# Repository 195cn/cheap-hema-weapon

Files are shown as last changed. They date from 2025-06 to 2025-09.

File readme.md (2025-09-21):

# 廉价HEMA武器计划

```
Author      : 195
Create Date : 2025/6/1

Version:     

    2025/9/21 V2.0 增加了武装剑，小圆盾。并且自研了免焊穿心刀根。
    2025/6/8  V1.1 实战测试，增加特大碗护手。
    2025/6/1  V1.0 初版军刀，圆盘D护版。

```

## 📜 开源声明（Unlicense协议）

本项目遵循 **[Unlicense协议](https://unlicense.org/)**，您享有完全自由的使用权：

- ✅ **无限制使用**：可自由复制、修改、分发，包括商业用途。
- ✅ **无需署名**：不强制要求保留作者信息或声明。
- ✅ **闭源兼容**：允许将本模型整合至闭源项目中。
- ⚠️ **法律免责**：  
  本作品按“现状”提供，**无任何明示或暗示担保**，包括但不限于：  
  - ✅ 适用性担保（不保证适用于您的特定场景）  
  - ✅ 安全性担保（不保证无漏洞或安全隐患）  
  - ✅ 合规性担保（不保证符合所有地区法律法规）  
  作者明确不承担因使用本模型产生的任何责任，包括但不限于直接损失、间接损失或法律纠纷。

## 不对任何安全问题负责，请自负一切后果

# 说明

DIY廉价入门装备，以满足对练需求。

非史诗设计，尽量采用现代工业的廉价材料。

在保证重心和减伤以外，尽量的便宜，不保证其他性能。

# Feature

- 总成本百元左右
- 刀条板材切割（淘宝代工方便）
- 护手板材切割/钣金（便宜，代工方便）
- ~~龙骨柄（穿心柄/老鼠尾需要焊接螺纹）~~
- 自研免焊穿心刀根
- 打印握把
- 打印安全头
- 加长握把（匹配195身高手型）

# 设计理念

本人并非Hema爱好者，而是生存狂菜刀党。
练hema的目的是储备械斗能力，以便在抢劫的时候用。
尽可能的避免双杀。
需要考虑室内作战，并且便于携带。
需要有压制常规生活武器的能力。
目标为城市非农非兵人口（打不过）。
因长枪和草叉等太过imba，不考虑单刀进枪之类的东西。

主要假想对向武器：
- 匕首
- 短棍
- 长棍
- 砍刀
- 柴刀/菜刀

并且要保证武器廉价易得，技术可复用到常见生活刀型，如卢旺达甘蔗刀，18剁等。

因大碗军刀独特的自带护手带来的绝佳防御，所以选择军刀作为技术基础。
而且在hema中联系人数较多，便于训练。

其实原来是练日刀的，因训练规矩太多，放弃了。
身体原因无法正坐，裸足训练，竹刀手感差异太大。

其他备选：
- 梅瑟德砍（护手容易制作）
- 手半剑（十字护手容易制作）
- 日刀（护手容易制作/大货多）

因个人体质问题，由于身高导致的手掌宽大，并且需要适应大号冰球手。
所以握把都相对较长。

# 版本

## V2.0

这是个里程碑的版本，以往最麻烦的刀根尾部焊接螺丝的问题得到了解决。

先用武装剑来进行测试，短期测试内，刀根并没有出现断裂等其他问题。

通过切割结构+螺纹杆+圆柱螺母，实现了免焊接的刀根尾部螺丝固定，这样就可以和史实刀剑一样固定剑格和配重球，或是护手。

### 武装剑

```

武装剑\V1\训练剑V1_65Mn硬料_3mm_20250907.dxf
武装剑\V1\细柄45mm球.stp
武装剑\V1\粗柄40mm球.stp

```

已经经过了实战测试。

模块化设计，可以自行改变剑柄（包括长度），剑格，配重，实现不同的重心配置。

剑条通过军刀刀条修改，减伤，手感无明显变化。增加指盾，重心稍微后移。

综合成本60左右。

材料清单： 

- 圆柱螺母x2 M6x12x10 (关键字 铁加长螺母圆柱螺母套管连接焊接螺母柱丝杆接头)
- 不锈钢球x1 直径38mm~45mm（关键字 304不锈钢实心打孔钢球带孔球通孔钻孔穿孔钢珠）
- M6螺纹杆 长度180mm
- M6垫片，六角螺母

重心：

- 用45mm不锈钢球配重，总重935g，重心5cm。
- 用38mm不锈钢球配重，总重785g，重心9cm。
- 还有40mm不锈钢球，没实际测，推测总重820g，重心7左右

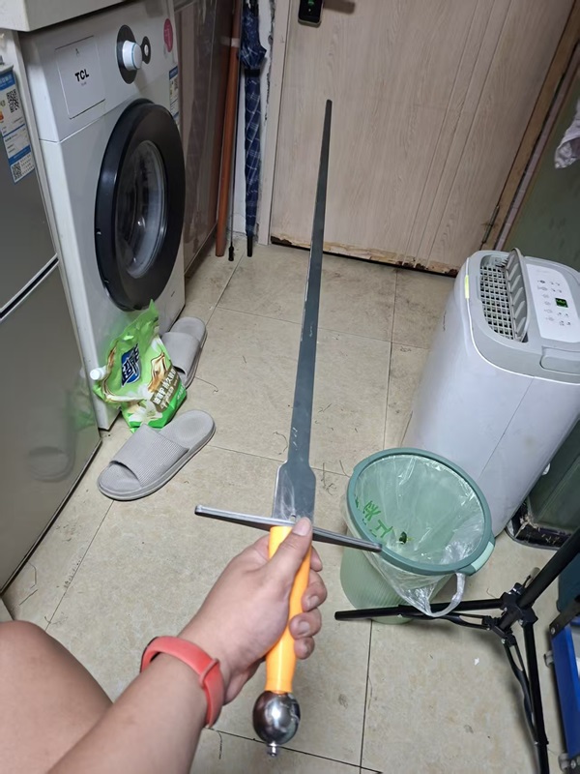
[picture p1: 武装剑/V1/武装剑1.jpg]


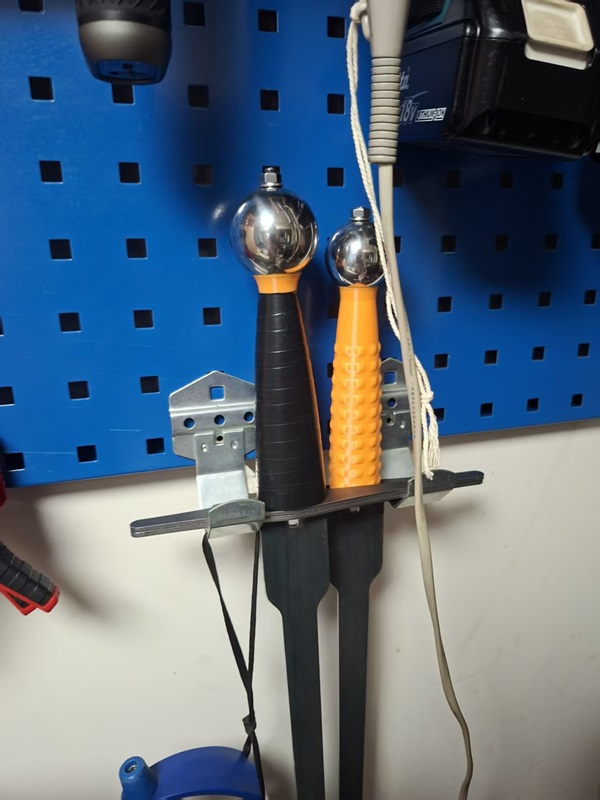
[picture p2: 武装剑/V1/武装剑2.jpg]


### 小圆盾

```

小圆盾\V1\训练盾V1_65Mn硬料_2mm_20250921.dxf
小圆盾\V1\圆盾把手.stp

```

未经过实战测试，打样途中。

全金属设计，盾帽使用不锈钢盆，并在盆底增加2mm厚的叠加甲片。

综合成本60左右。

材料清单： 

- 肉蟹煲盆 直径22cm (关键字 胖哥俩馋胖不锈钢肉蟹煲专用盆商用虾蟹煲盆酸菜鱼水煮鱼小龙虾盆)

木制版本测试后发现工序过于复杂，但是手感尚可。

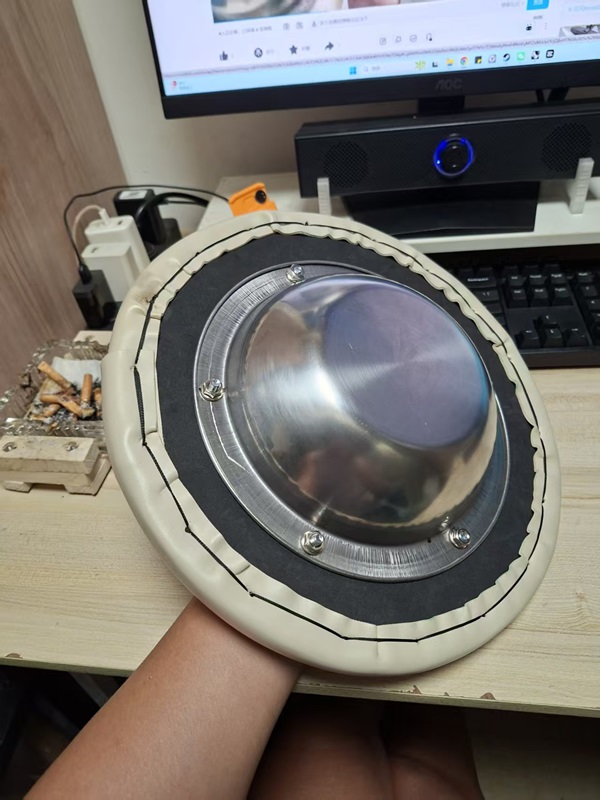
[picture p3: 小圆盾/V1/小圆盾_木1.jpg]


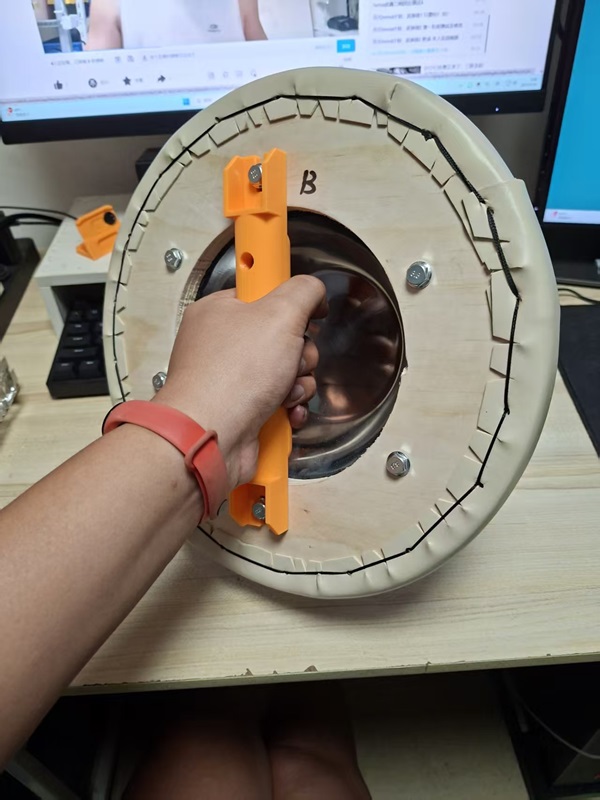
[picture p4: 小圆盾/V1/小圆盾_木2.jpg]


### 军刀

未改动，移动到独立文件夹。

暂时没有日程修改。不过最近测试了喷枪热弯，似乎可以用于自制军刀D护。

我个人不建议做这个版本了，缺点太多了。

### 通用模型

通过刀根开槽，卡住两个圆柱螺母，并且通过打印刀柄内部开槽实现了约束。

可以自由调整螺纹杆的长度，以配合不同刀柄。

V1,V2 所需的圆柱螺母尺寸为： M6x12x10 (关键字 铁加长螺母圆柱螺母套管连接焊接螺母柱丝杆接头)

- 基础刀根——测试用，为原军刀刀根，已废弃。
- 通用刀根V1，较细的早期版本，装配测试过，但处于强度考虑，武装剑没有采用。
- 通用刀根V2，武装剑加粗版本，已实战测试。

通用刀根V2的刀根宽处为26mm，手柄宽度最小建议32mm以上。

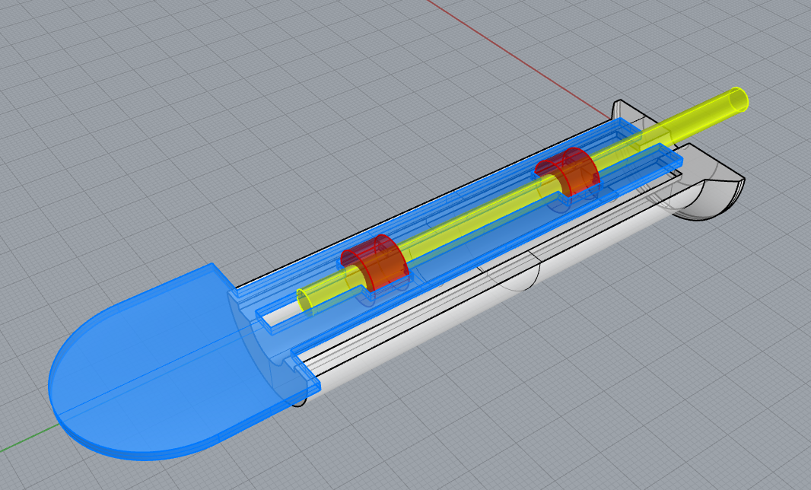
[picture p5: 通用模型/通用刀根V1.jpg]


## V1.1

经过实战测试。

- 刺击减伤和斩击减伤都得到认可。
- 刀身有点弹，但普遍可以接受。
- 两个护手版本，评价还算可以。
- 握把太圆太细，待修改
- 安全头强度不够，待修改。

### 护手

增加了特大碗,碗重615g，总重1150g，重心8cm。

经过测试，手感评价可以，防护力非常好。

虽然很重，但是还是放出来供参考。

```
V1\护手_002_特大碗.stp
```

## V1

整体重量900g左右，重心13cm。

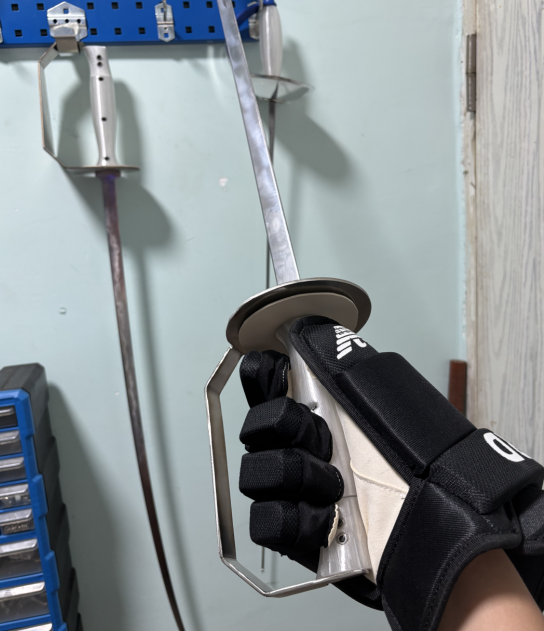
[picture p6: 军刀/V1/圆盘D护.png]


为下图最后两把“圆盘D护”

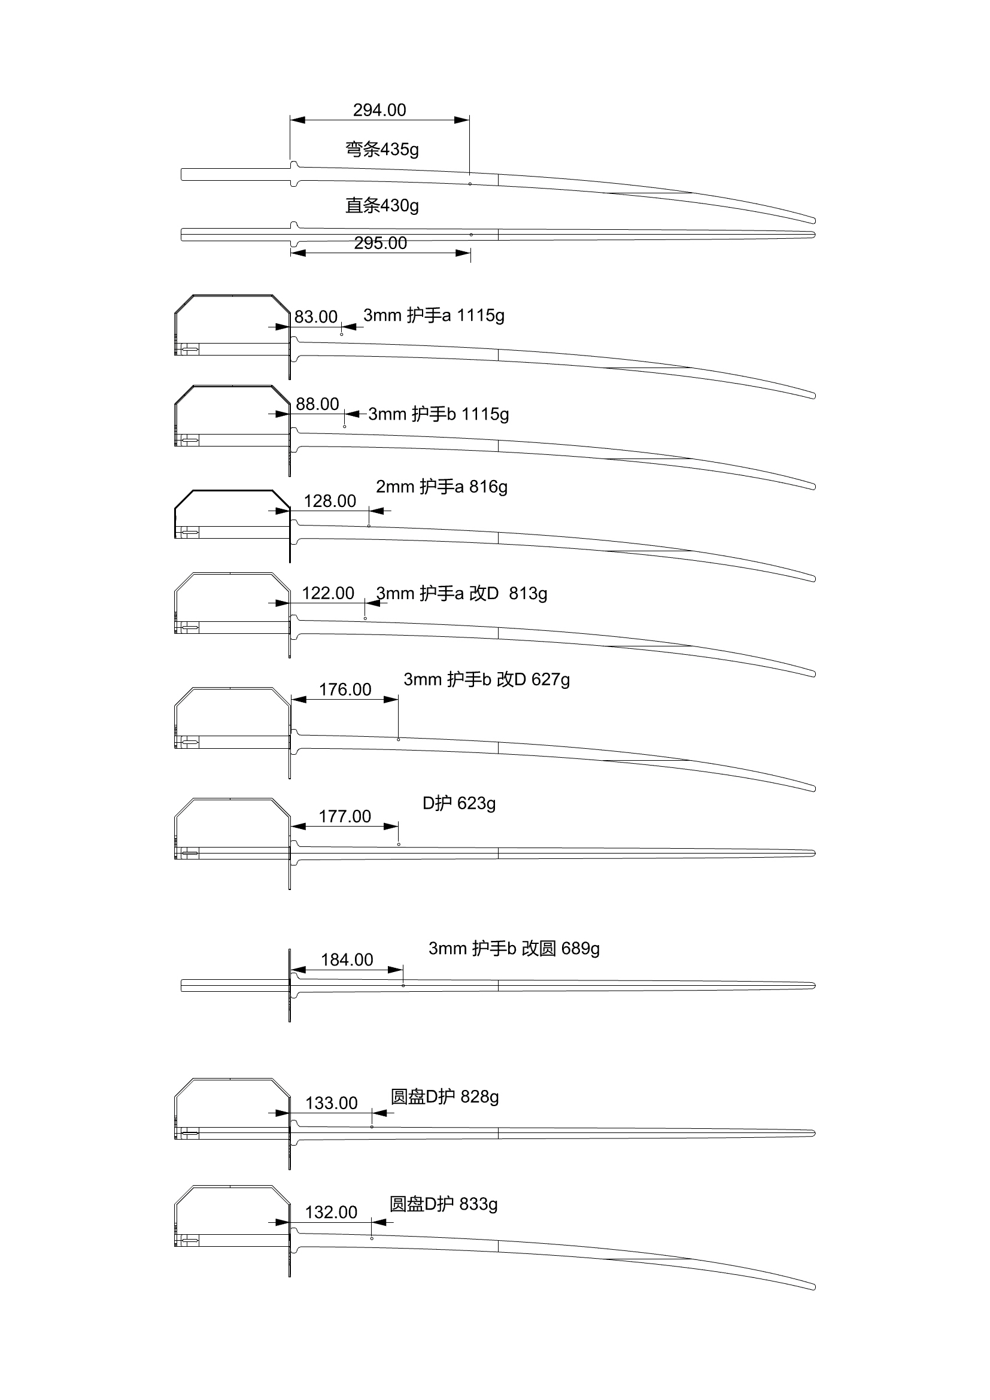
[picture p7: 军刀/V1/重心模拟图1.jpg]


### 刀条

分别设计了直刀和弯刀，材质为3mm厚的65Mn（弹簧钢）淬火硬料。

```
V1\弯刀条_3mm_65Mn硬料.dxf
V1\直刀条_3mm_65Mn硬料.dxf
```

- 龙骨刀根
- 刺击减伤9.5kg
- 斩击减伤**未测试**

### 护手

找淘宝可以接受stp模型的钣金代工商家，我不会画钣金图。

材质测试用的304不锈钢，但A3，弹簧钢应该都可以。

```
V1\护手_001_圆盘D护.stp
```

打样了2种护手，3mm厚不锈钢，重量为615g左右，过重。

重心问题比较严重，重心严重偏离刀身，转动惯量过大。

临时用角磨机切割了一个，重量减少为410g左右。

经测试手感良好。

模型为切割后的版本，但感觉不伦不类的，已经不是军刀的大碗了，更像spadroon。

### 握把

建议壁厚4，填充20%。

```
V1\大碗通用握把_V1.stp
```

纺锤形，尽量贴近实战型而不是竞技型。

用M4柱头螺栓和六角螺母固定，长度忘了应该是M4*18吧，忘了，你们多买几种吧，嘻嘻。

握把和护手中间需要垫一块厚度1mm~1.5mm的皮革或者其他布料，面巾纸也行。

护手开槽长22mm，刀根宽20mm，为了便于安装，这就造成了装好后护手会前后动。

搞个东西压在握把和护手中间，就可以增加摩擦力，也可以防止拇指磕到护手。

# 计划

## V1阶段（已完成）

尝试65Mn均厚刀条是否可以用于兵击训练。

- 65Mn弹簧钢均厚刀条（完成）
- 刺击减伤测试（完成）
- 斩击减伤测试（V1.1完成）
- 空挥手感测试（V1.1完成）
- 实战测试（V1.1完成）
- 钣金护手（算完成了，这个版本就这样）
- 打印安全头（完成，测试耐久不高）
- 打印握把（完成）
- 大碗护手重新设计
- 握把优化
- 其他潜在的优化

需要实战训练，咨询馆内兵击老手意见。

预计空挥一个月，对练两场。

优化整体设计，对标400~800水平大货军刀。

## V2阶段（进行中）

了解梅瑟，手半剑，中剑等结构，调研/打样。

- 直剑+十字格类型（完成）
- 大弧度刀条，波刀
- 反曲刀刀条
- 德砍

## V3阶段

开刃试斩，刀鞘携具。

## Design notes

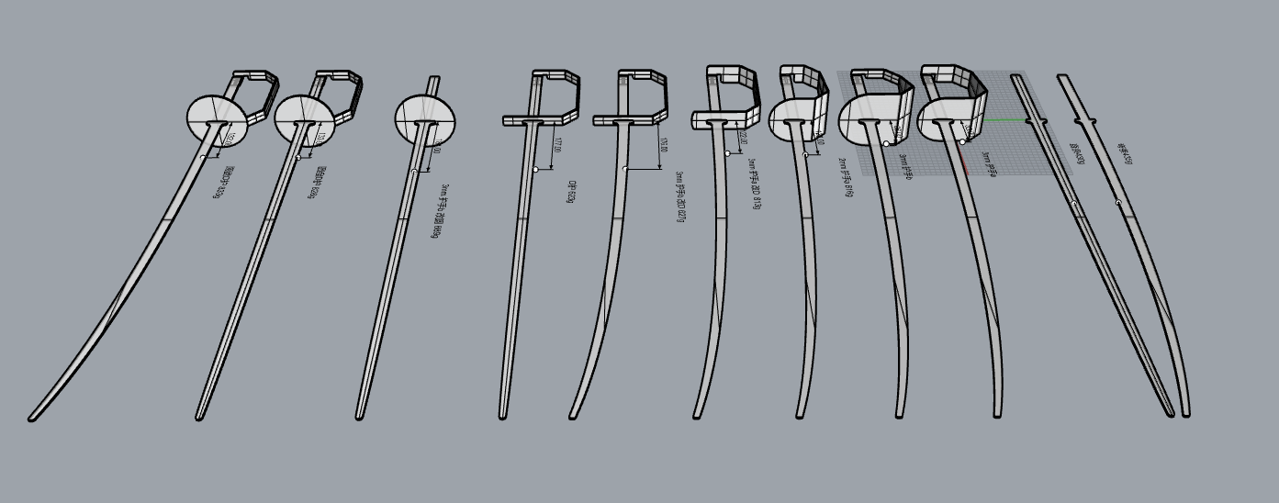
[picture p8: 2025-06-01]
军刀/V1/重心模拟图2.png

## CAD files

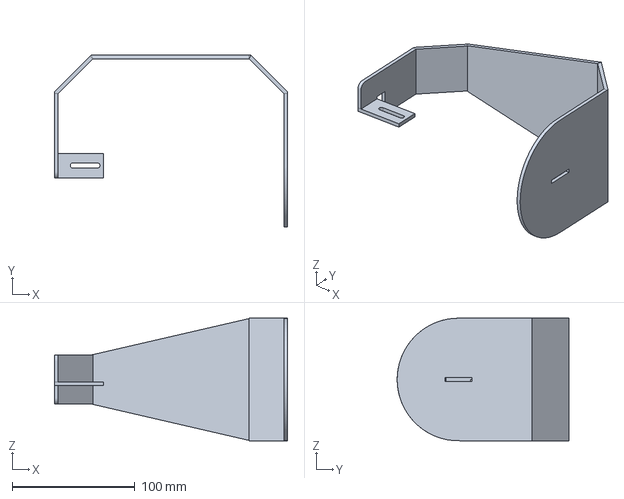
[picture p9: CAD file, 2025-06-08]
军刀/V1/护手_002_特大碗.stp
190.0 x 140.0 x 100.0 mm

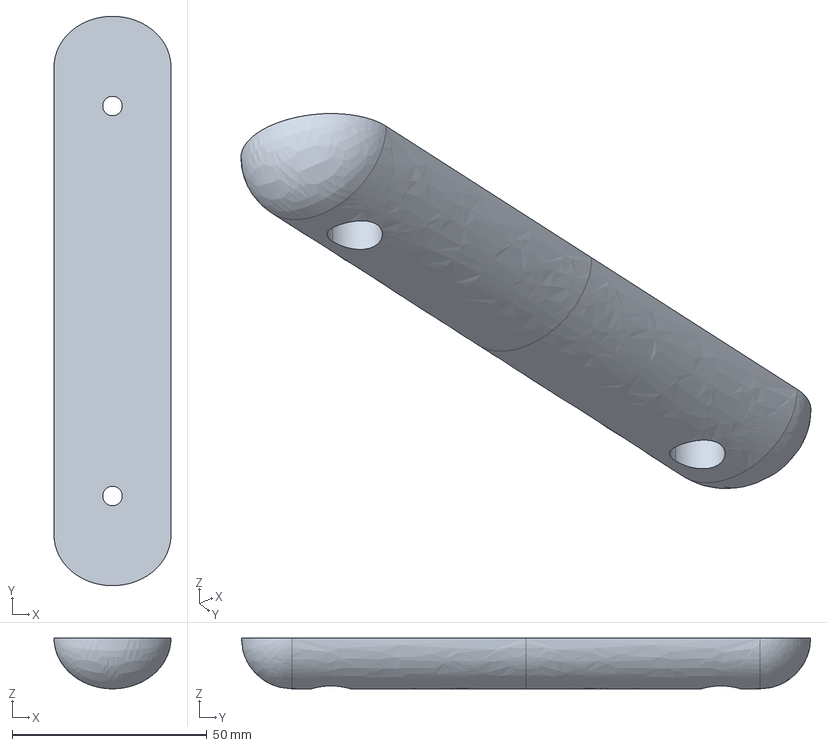
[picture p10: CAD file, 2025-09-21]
小圆盾/V1/圆盾把手.stp
30.0 x 146.0 x 13.0 mm

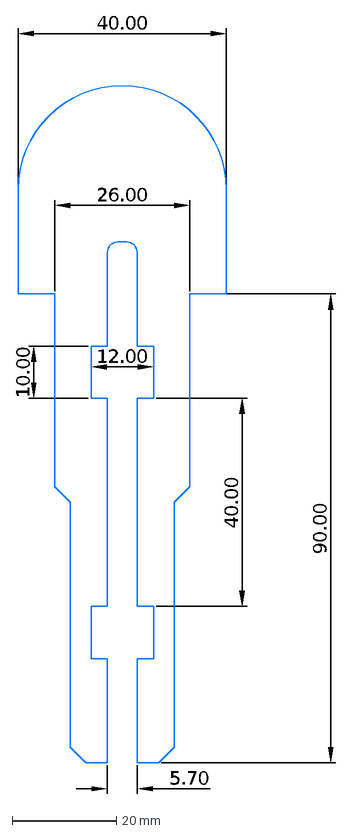
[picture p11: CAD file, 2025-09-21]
通用模型/通用刀根V2.dxf
40.00
5.70
10.00
12.00
90.00
26.00

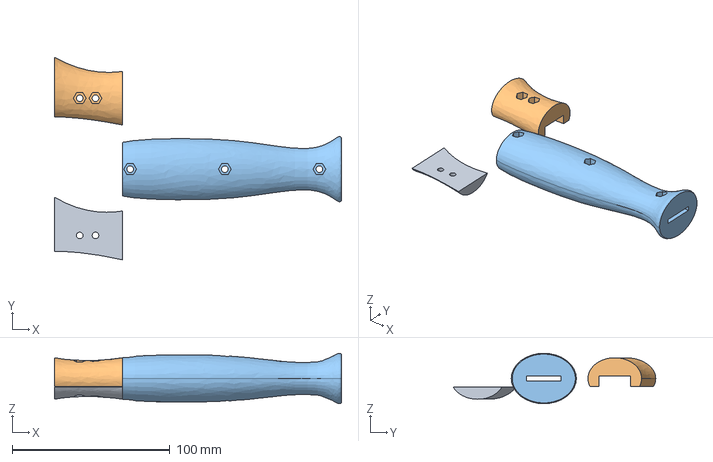
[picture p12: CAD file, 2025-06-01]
军刀/V1/大碗通用握把_V1.stp
182.0 x 128.4 x 32.0 mm

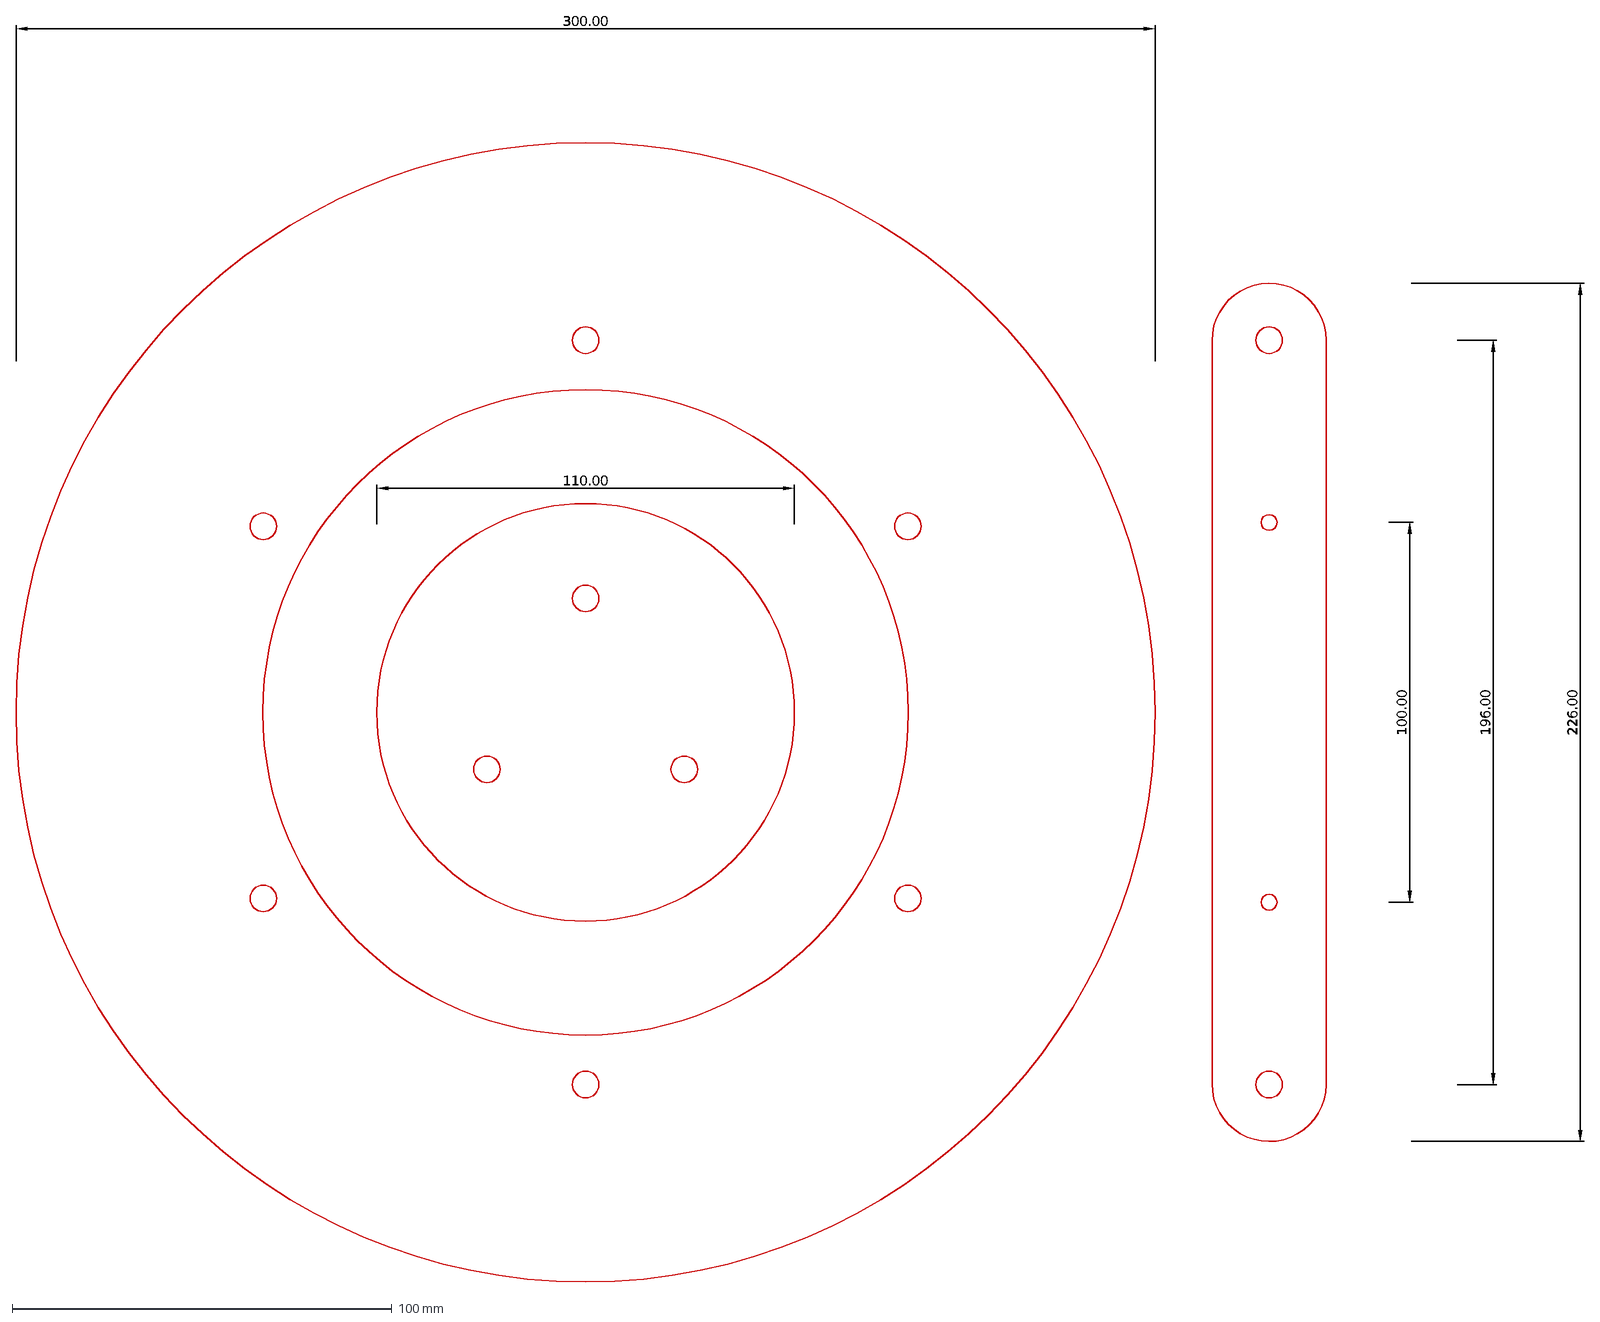
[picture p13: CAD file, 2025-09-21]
小圆盾/V1/训练盾V1_65Mn硬料_2mm_20250921.dxf
110.00
100.00
196.00
226.00
300.00

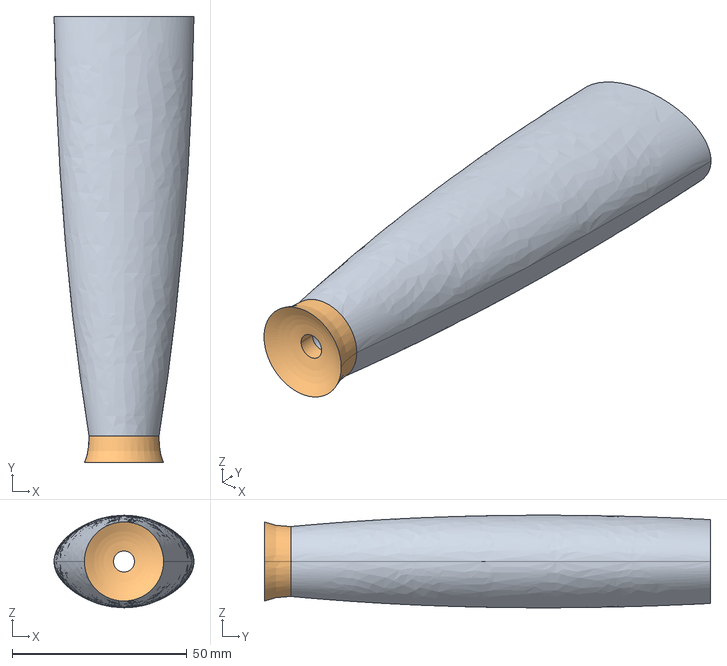
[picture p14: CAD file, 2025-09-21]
武装剑/V1/粗柄40mm球.stp
40.0 x 127.5 x 26.5 mm

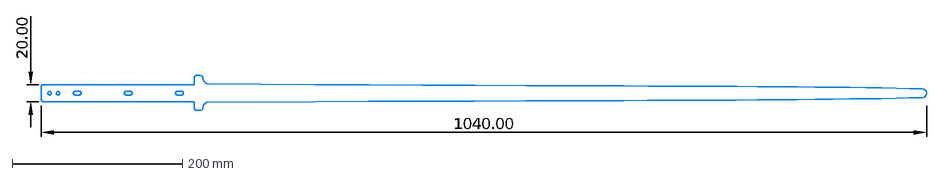
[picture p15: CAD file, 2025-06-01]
军刀/V1/直刀条_3mm_65Mn硬料.dxf
1040.00
20.00

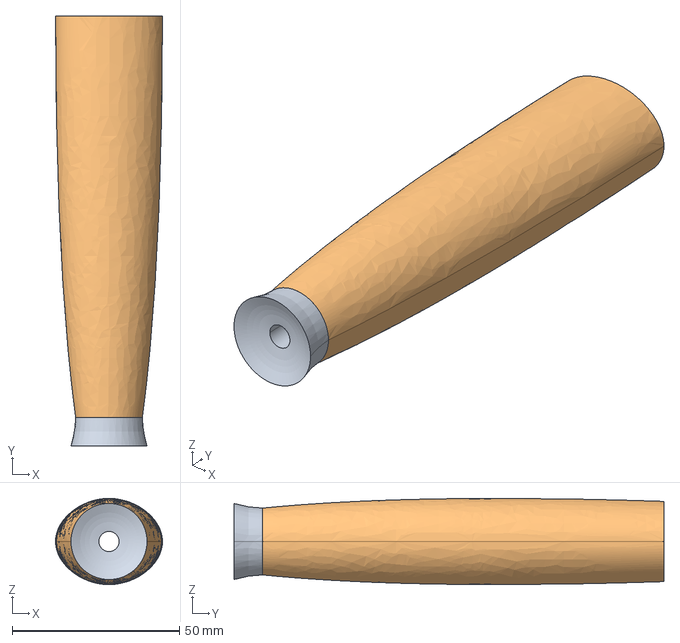
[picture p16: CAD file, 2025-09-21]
武装剑/V1/细柄45mm球.stp
32.0 x 128.6 x 25.8 mm

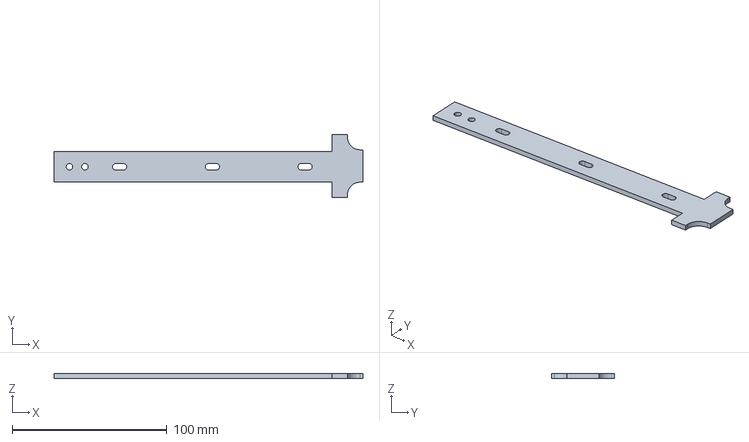
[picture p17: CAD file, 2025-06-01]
通用模型/基础刀根_测试用.stp
200.0 x 41.0 x 3.00 mm

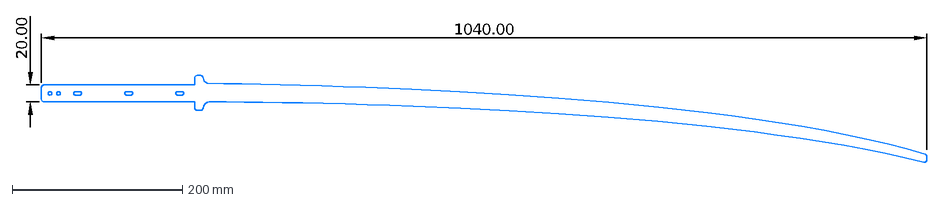
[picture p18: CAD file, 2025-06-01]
军刀/V1/弯刀条_3mm_65Mn硬料.dxf
1040.00
20.00

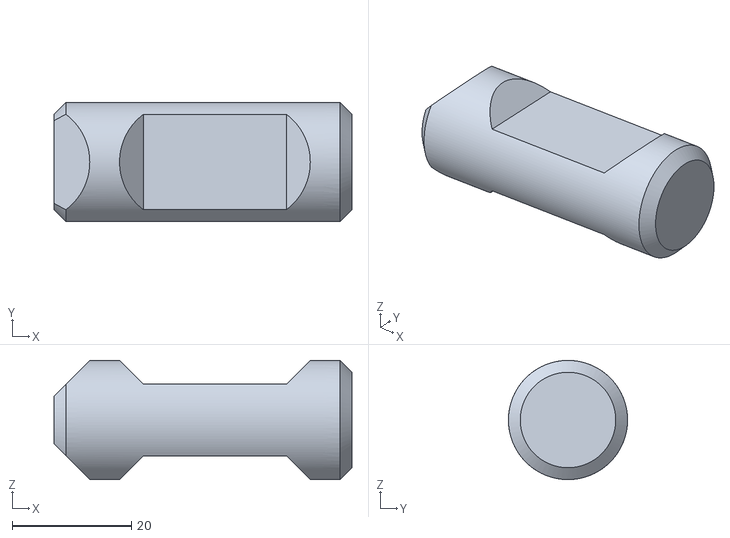
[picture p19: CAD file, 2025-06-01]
通用模型/hema安全头.stl
50.0 x 20.0 x 20.0

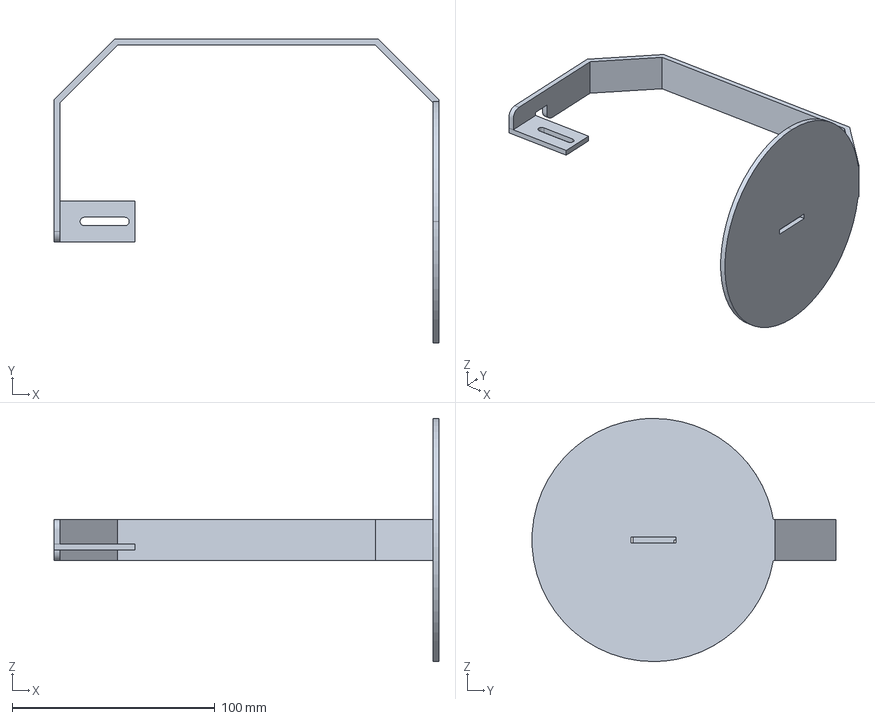
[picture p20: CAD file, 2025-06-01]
军刀/V1/护手_001_圆盘D护.stp
190.0 x 149.9 x 120.0 mm

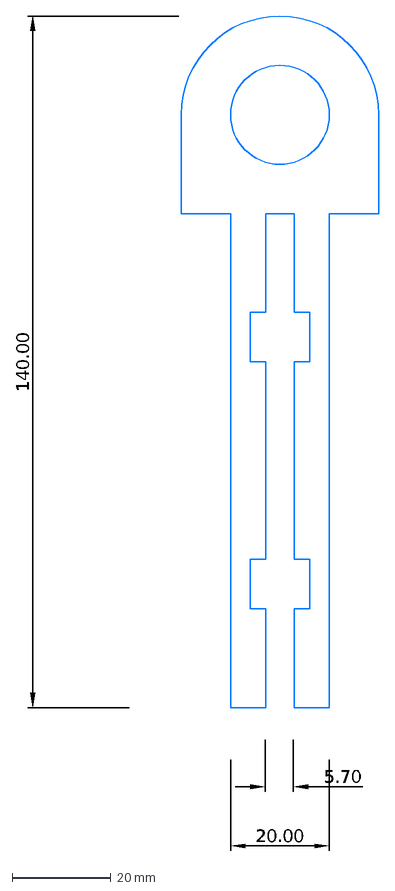
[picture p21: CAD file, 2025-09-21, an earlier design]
通用模型/通用刀根V1.dxf
140.00
5.70
20.00

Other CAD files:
武装剑/V1/训练剑V1_65Mn硬料_3mm_20250907.dxf
